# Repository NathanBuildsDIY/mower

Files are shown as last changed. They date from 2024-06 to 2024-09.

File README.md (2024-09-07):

# mower
This is the installation files for version 2 of my automated robot mower. Learn more at the youtube link here:

To set up your raspberry pi zero 2 w

1. If you log in via ssh and it hangs, improve ssh response times with this command and then reboot: echo "IPQoS cs0 cs0" | sudo tee -a /etc/ssh/sshd_config

2. install git on your raspberry pi: sudo apt-get -y install git

3. clone this git repository to your pi home directory: git clone https://github.com/NathanBuildsDIY/mower

4. Run initial setup: nohup sh weeder/initial-setup.sh & Note - you can watch the output with: tail -f nohup.out

5. Connect to the new wifi hostpot called mower. Visit http://mower.local to control your mower.  You can still ssh to the mower (while connected to the mower wifi) via ssh or putty, hostname mower.local

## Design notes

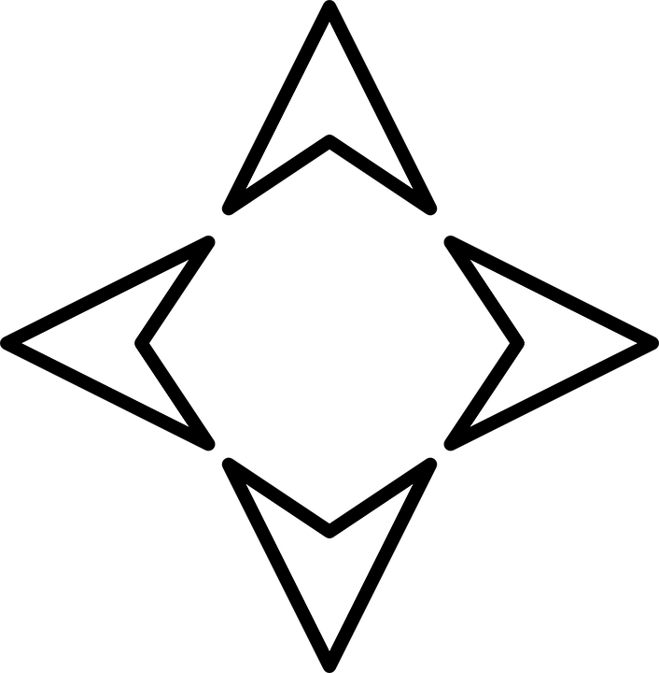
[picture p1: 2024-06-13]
templates/arrows-40162_960_720.png

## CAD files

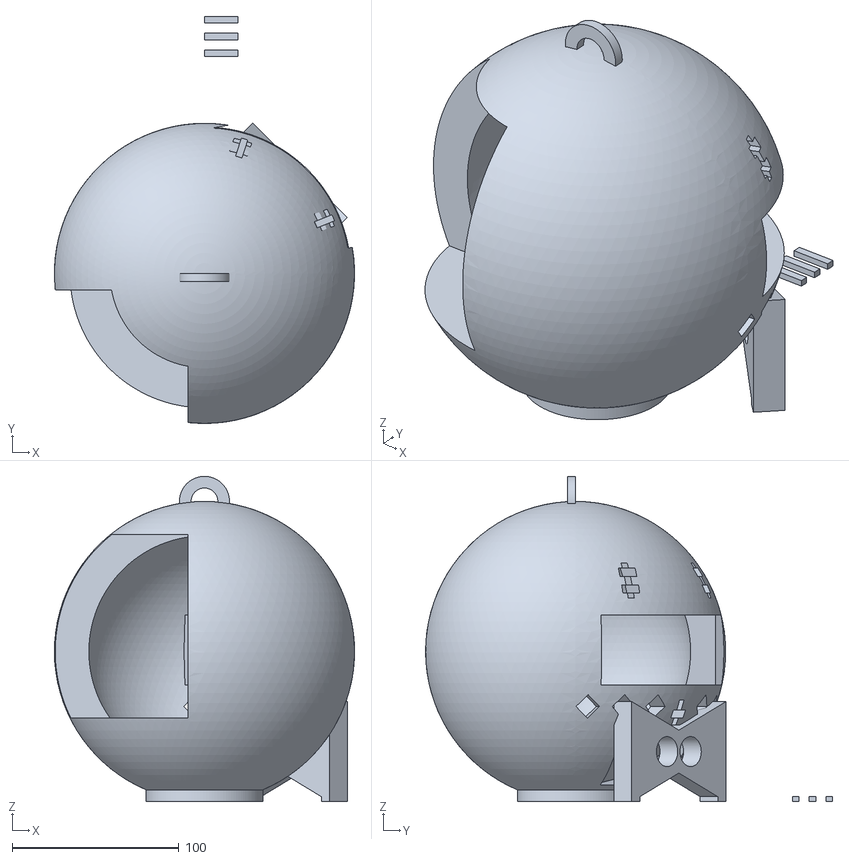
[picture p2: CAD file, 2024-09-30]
ghost_v1.stl
179.9 x 244.0 x 195.0

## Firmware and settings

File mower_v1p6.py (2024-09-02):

#Control for hoverboard function. riorand board. from: #https://mad-ee.com/controlling-a-hoverboard-motor-with-a-simple-arduino/
#run with python3 -m flask --app mower/mower_v1pX.py run --host=0.0.0.0
#1.2 - v2 printed control arms. balance forward w/ curve
#1.3 - forward balance wheels function in robot class, ratio
#1.4 - echo location sensors
#1.5 - 4 wheel drive
#1.6 - pigpio factory. space out readings

# import the necessary packages
from flask import Flask, render_template
import math
import numpy as np
import os
from glob import glob
import time
from datetime import datetime
from gpiozero import Device, PhaseEnableMotor, Robot, PhaseEnableRobot, LED, Servo, AngularServo, Button, DistanceSensor
from gpiozero.tools import zip_values
from gpiozero.pins.pigpio import PiGPIOFactory  
#import py_qmc5883l
from threading import Thread

#TO DO: add object detect/emergency off.
#TO DO: Speed up wheels as battery drains. Count time / wheel turns
#TO DO: auto throttle-off safety. emergency off switch for start/stop on mower.
autoMode=0 #manual mode to start
flask=1 #flask is turned on - so we always start website
speed=0.5 #this is how fast of max (1) we should go. Can adjust if too fast or slow with your wheels. Make programmable?
timeBetweenSensorReads=0.0 #time to wait between reading sensors
timeToFlushSensorHistory=0.85 #how long it will take to completely clear out the sensor array history (how fast the mower reacts to changes in terrain/grass line)
currentCurve_left = 0 #using this as a steering bias if not straight
currentCurve_right = 0
backAdjust_right = 0 #adjust speed of back wheels vs front
backAdjust_left = 0
reactivity = 1 #0 to 1, shows how quickly to react to motors not turning the same speed
max_sensor_distance = 2.0
backWheelAdjust = 1.1 #my back wheels are from a v2 hoverboard and radius is smaller than front. Adjust speed accordingly to cover same distance for front and back tires

#define the wheels and brake pins
brake = LED(14)
brake.off() #this sets nobrake pin high which turns off brake
factory = PiGPIOFactory()
MotorL=PhaseEnableMotor(15,18,pin_factory=factory) #dir,pwm
MotorLBack=PhaseEnableMotor(11,10,pin_factory=factory)
MotorR=PhaseEnableMotor(8,13,pin_factory=factory)
MotorRBack=PhaseEnableMotor(25,22,pin_factory=factory)
MotorLSpeedPin = Button(23); MotorLSpeed = 0
MotorRSpeedPin = Button(7); MotorRSpeed = 0
MotorLBackSpeedPin = Button(9); MotorLBackSpeed = 0
MotorRBackSpeedPin = Button(27); MotorRBackSpeed = 0

#define the sensors
#leftBump = Button(17) #Left bumper, normally True
#rightBump = Button(1) #Right bumper, normally True
rightGrass = DistanceSensor(echo=12, trigger=16, max_distance=max_sensor_distance,pin_factory=factory) #Right grass, normally False
rightCenterGrass = DistanceSensor(echo=20, trigger=21, max_distance=max_sensor_distance,pin_factory=factory) #Right Center grass, normally False
leftGrass = DistanceSensor(echo=19, trigger=26, max_distance=max_sensor_distance,pin_factory=factory) #Left Center grass, normally False
leftCenterGrass = DistanceSensor(echo=6, trigger=5, max_distance=max_sensor_distance,pin_factory=factory) #Left grass, normally False
currentTime=datetime.now()

#Use this with object detect/avoid - need to turn a know number of degrees to go around stuff
'''#define the compass.  Here's some notes about it. It's not HMC as advertised
#from https://forums.raspberrypi.com//viewtopic.php?f=28&t=172244 -- this is QMC not HMC, that's not made any more bottom of page get drivers: https://github.com/RigacciOrg/py-qmc5883l
#PINS: vcc (yellow) -> 3.3V pin1.  Gnd Green -> Gnd pin 9.  orange SCL -> GPIO3 (pin5). red SDA->GPIO2 (pin3). DRDY unused.
#Don't connect drdy to any wire, it caused xy axis to shift to yz axis. compass broke!
#Enable I2C: sudo raspi-config (activate it under interfaces->i2c)
#Check connected up: sudo i2cdetect -y 1  (see output) - 0d address
#cd ~/mower/; git clone https://github.com/RigacciOrg/py-qmc5883l
#add py-qmc5883l to python path variable
  #sudo vi /etc/profile
  #At the top add these two lines (adjust path if necessary):
  #export ADDPATH=/home/gibby/mower/py-qmc5883l
  #export PYTHONPATH=$PYTHONPATH:$ADDPATH
  #reboot
#sensor = py_qmc5883l.QMC5883L()
#m = sensor.get_magnet()
#print(m)
'''

#easier to define our own since we have specific needs for forward (balance all 4 wheel rotation speeds) etc.
class mowerRobot:
  def __init__(self, leftMotor, rightMotor, leftBackMotor, rightBackMotor):
    self.left_motor=leftMotor
    self.right_motor=rightMotor
    self.leftBack_motor=leftBackMotor
    self.rightBack_motor=rightBackMotor
  def forward(self, speed=1, *, curve_left=0, curve_right=0, previousCommand="straight", command="straight", intentionalAngle=False):
    global MotorRSpeed, MotorLSpeed, MotorRBackSpeed, MotorLBackSpeed, currentCurve_right, currentCurve_left,backAdjust_right, backAdjust_left
    saveCounts=""
    #check if wheels are turning at the same speed. 
    if (previousCommand == "straight" and command == "straight") or (previousCommand == "angleR" and command == "angleR") or (previousCommand == "angleL" and command == "angleL"):
      saveCounts = "FRC: "+str(MotorLSpeed)+" FRC: "+str(MotorRSpeed)+" BLC: "+str(MotorLBackSpeed)+" BRC: "+str(MotorRBackSpeed)
      #we've been going straight for at least 2 commands, or angling for 2 commands. We can check wheel counts and recalculate speeds if counts are high enough.
      if MotorRSpeed > 25 or MotorLSpeed > 25:
        #only recalculate if we have enough turns to call it "valid". Start with front wheels
        if MotorRSpeed*(1-curve_left) < MotorLSpeed*(1-curve_right):
          #right side is turning slower. add to right speed or subtract from left
          #If command=straight curve_left and right are 0 so its direct wheel compare. 
          #If command=angleL motorRSpeed (count of wheel turns on front R) shoudl be bigger, curve_left is .2 so it's motorRSpeed * .8 compared to motorLSpeed. angleR vice versa
          adder = round((MotorLSpeed*(1-curve_right)) / ((MotorRSpeed+1)*(1-curve_left)) * speed - speed,2) * reactivity
          if currentCurve_left > 0:
            currentCurve_left = round(currentCurve_left - adder,2)
            currentCurve_right = 0
          else:
            currentCurve_right = round(currentCurve_right + adder,2)
            currentCurve_left = 0
        if MotorRSpeed*(1-curve_left) > MotorLSpeed*(1-curve_right):
          #left side is turning slower. add to left side speed or subtract from right
          adder = round((MotorRSpeed*(1-curve_left)) / ((MotorLSpeed+1) * (1-curve_right)) * speed - speed,2) * reactivity
          if currentCurve_right > 0:
            currentCurve_right = round(currentCurve_right - adder,2)
            currentCurve_left = 0
          else:
            currentCurve_left = round(currentCurve_left + adder,2)
            currentCurve_right = 0
        if currentCurve_left < 0:
          currentCurve_left = 0 #we can get negatives if we subtract as such above, can't set curve negative
        if currentCurve_right < 0:
          currentCurve_right = 0
        #Now figure out back wheel speeds
        backAdjust_right = round(((MotorRSpeed*backWheelAdjust)/(MotorRBackSpeed+1) - 1) * reactivity/4,2) #positive if front wheel is too fast, so add ot back wheel speed
        backAdjust_left = round(((MotorLSpeed*backWheelAdjust)/(MotorLBackSpeed+1) - 1) * reactivity/4,2)
        #we corrected speeds. Reset counts to 0
        MotorRSpeed = 0; MotorLSpeed = 0; MotorLBackSpeed = 0; MotorRBackSpeed = 0
        #saveCounts = saveCounts +" Adj+0 "
    else:
      #just moved from turning or backing or something else to straight. don't pay attention to wheel counts, instead 0 them out and start recounting
      MotorRSpeed = 0; MotorLSpeed = 0; MotorLBackSpeed = 0; MotorRBackSpeed = 0
      saveCounts = "FRC: "+str(MotorLSpeed)+" FRC: "+str(MotorRSpeed)+" BLC: "+str(MotorLBackSpeed)+" BRC: "+str(MotorRBackSpeed)+" 0-dir "
    saveCounts = saveCounts+" FRA: "+str(currentCurve_right)+" FLA: "+str(currentCurve_left)+" BRA: "+str(backAdjust_right)+" BLA: "+str(backAdjust_left)
    #execute the drive command with the calculated values after error checks
    if not 0 <= curve_left <= 1:
      raise ValueError('curve_left must be between 0 and 1')
    if not 0 <= curve_right <= 1:
      raise ValueError('curve_right must be between 0 and 1')
    if curve_left != 0 and curve_right != 0:
      raise ValueError("curve_left and curve_right can't be used at the same time")
    frontLeftSpeed = round((speed + currentCurve_left) * (1 - curve_left),2)
    frontRightSpeed =round((speed + currentCurve_right) *(1 - curve_right),2)
    backLeftSpeed = round(frontLeftSpeed + backAdjust_left,2)
    backRightSpeed = round(frontRightSpeed + backAdjust_right,2)
    if not 0 <= frontLeftSpeed:
      frontLeftSpeed = 0
    if not frontLeftSpeed <= 1:
      frontLeftSpeed = 1
    if not 0 <= frontRightSpeed:
      frontRightSpeed = 0
    if not frontRightSpeed <=1:
      frontRightSpeed = 1
    if not 0 <= backLeftSpeed:
      backLeftSpeed = 0
    if not backLeftSpeed <=1:
      backLeftSpeed = 1
    if not 0 <= backRightSpeed:
      backRightSpeed = 0
    if not backRightSpeed <=1:
      backRightSpeed = 1
    self.left_motor.forward(frontLeftSpeed); 
    self.right_motor.forward(frontRightSpeed);
    self.leftBack_motor.forward(backLeftSpeed)
    self.rightBack_motor.forward(backRightSpeed)
    return "F-FLS:"+str(frontLeftSpeed)+" FRS:"+str(frontRightSpeed)+" BLS:"+str(backLeftSpeed)+" BRS:"+str(backRightSpeed)+" ",saveCounts
  def backward(self, speed=1, *, curve_left=0, curve_right=0):
    global MotorRSpeed, MotorLSpeed, MotorRBackSpeed, MotorLBackSpeed, currentCurve_right, currentCurve_left,backAdjust_right, backAdjust_left
    frontLeftSpeed = round((speed + currentCurve_left) * (1 - curve_left),2)
    frontRightSpeed =round((speed + currentCurve_right) *(1 - curve_right),2)
    backLeftSpeed = round(frontLeftSpeed + backAdjust_left,2)
    backRightSpeed = round(frontRightSpeed + backAdjust_right,2)
    if not 0 <= frontLeftSpeed:
      frontLeftSpeed = 0
    if not frontLeftSpeed <= 1:
      frontLeftSpeed = 1
    if not 0 <= frontRightSpeed:
      frontRightSpeed = 0
    if not frontRightSpeed <=1:
      frontRightSpeed = 1
    if not 0 <= backLeftSpeed:
      backLeftSpeed = 0
    if not backLeftSpeed <=1:
      backLeftSpeed = 1
    if not 0 <= backRightSpeed:
      backRightSpeed = 0
    if not backRightSpeed <=1:
      backRightSpeed = 1
    self.left_motor.backward(frontLeftSpeed); 
    self.right_motor.backward(frontRightSpeed);
    self.leftBack_motor.backward(backLeftSpeed)
    self.rightBack_motor.backward(backRightSpeed)
    print("B-FLS:",str(frontLeftSpeed),"FRS:",str(frontRightSpeed),"BLS:",str(backLeftSpeed),"BRS:",str(backRightSpeed),"FLC:",MotorLSpeed,"FRC:",MotorRSpeed,"BLC:",MotorLBackSpeed,"BRC:",MotorRBackSpeed)
  def left(self, speed=1):
    global MotorRSpeed, MotorLSpeed, MotorRBackSpeed, MotorLBackSpeed, currentCurve_right, currentCurve_left,backAdjust_right, backAdjust_left
    self.left_motor.backward(1)
    self.right_motor.forward(1)
    self.leftBack_motor.backward(1)
    self.rightBack_motor.forward(1)
    print("L-FLS:1.0 FRS:1.0 BLS:1.0 BRS:1.0")
  def right(self, speed=1):
    global MotorRSpeed, MotorLSpeed, MotorRBackSpeed, MotorLBackSpeed, currentCurve_right, currentCurve_left,backAdjust_right, backAdjust_left
    self.left_motor.forward(1)
    self.right_motor.backward(1)
    self.leftBack_motor.forward(1)
    self.rightBack_motor.backward(1)
    print("R-FLS:1.0 FRS:1.0 BLS:1.0 BRS:1.0ba")
  def stop(self):
    self.left_motor.stop()
    self.right_motor.stop()
    self.leftBack_motor.stop()
    self.rightBack_motor.stop()
    print("S-FLS:0.0 FRS:0.0 BLS:0.0 BRS:0.0")
robot = mowerRobot(MotorL,MotorR,MotorLBack,MotorRBack)

#useful functions
#To be used with compass and object detect/avoid
'''def turnMower(direction,degrees):
  initialCompass=sensor.get_bearing()
  currentCompass=initialCompass
  if direction == "right":
    robot.right(speed); 
  else:
    robot.left(speed);
  while abs(initialCompass-currentCompass) % 360 < degrees or abs(initialCompass-currentCompass) % 360 > (360-degrees):
    time.sleep(0.02); 
    currentCompass=sensor.get_bearing()
  print("initial compass:",str(initialCompass),"currentCompass",str(currentCompass),"difference",str(abs(initialCompass-currentCompass)%360))
'''
def sensorWeightedAverage(grassSensor):
  global grassSide
  numMeasurements=len(grassSensor) #number of measurements
  numSensors=len(grassSensor[0]) #number of sensors on mower
  #get the weights based on number of measurements
  linArr = np.arange(1, numMeasurements+1)
  arrSum = numMeasurements * (numMeasurements+1) // 2
  reverseWeights = linArr/arrSum
  #row by row add up the weighted values in columns
  weightedGrassSensor = [0] * numSensors
  for (i,row) in enumerate(grassSensor):
    for (j,value) in enumerate(row):
      if value == max_sensor_distance * 100:
        value = 2.0 #we only get max sensor distance when no echo comes back, because grass is pressed right up on sensor. Correct for this
      weightedGrassSensor[j]=weightedGrassSensor[j]+reverseWeights[numMeasurements-1-i]*value
  #sum up the values in columns - unused
  #sumGrassSensor=[sum(x) for x in zip(*grassSensor)]
  for i in range(numSensors):
    weightedGrassSensor[i]=round(weightedGrassSensor[i],2)
  return weightedGrassSensor

#Add back in with object detect/avoid
'''
#interrupts wheels and obstacles.  Take over wheels to move around obstacle.
def opticalBumpPress(initiator):
  global grassSide, interrupt, brake, robot, leftBump, rightBump
  duration = 1 #number of seconds to drive sideways to avoid the obstacle
  print("Starting avoidance routine, bumped by:",initiator)
  if interrupt == 0:
    interrupt=1 #tells the robot to stop doing other stuff
    #First try to back up and ensure the beam break is undone. If it's not, just stop. Could be the operator wants to stop the robot
    print("avoid obstacle - #1 brake"); brake.on(); time.sleep(0.1); robot.stop(); brake.off(); #first, stop things
    print("2 back up"); robot.backward(speed); time.sleep(2); brake.on(); time.sleep(0.1); robot.stop(); brake.off(); #second back up
    if leftBump.is_pressed and rightBump.is_pressed:
      print("3 turn opposite ",grassSide)
      if grassSide == "left":
        turnMower("right",90)
      else:
        turnMower("left",90)
      brake.on(); time.sleep(0.1); robot.stop(); brake.off(); #third turn 90
      print("4 forward for ",str(duration)); robot.forward(speed); time.sleep(duration); brake.on(); time.sleep(0.1); robot.stop(); brake.off(); #fourth drive forward (around obstacle)
      print("5 turn ",grassSide)
      turnMower(grassSide,90)
      time.sleep(1); brake.on(); time.sleep(0.1); robot.stop(); brake.off(); #fifth turn 90 back to original direction 
      print("6 return control to main loop")
    else:
      print("can't reestablish the bumper connection after backup, quitting")
      autoMode = 0
      robot.stop()
  interrupt = 0
  return
'''
def MotorLSpeedCount():
  global MotorLSpeed, MotorLSpeedPin
  MotorLSpeed = MotorLSpeed + 1
def MotorRSpeedCount():
  global MotorRSpeed, MotorRSpeedPin
  MotorRSpeed = MotorRSpeed + 1
def MotorLBackSpeedCount():
  global MotorLBackSpeed, MotorLBackSpeedPin
  MotorLBackSpeed = MotorLBackSpeed + 1
def MotorRBackSpeedCount():
  global MotorRBackSpeed, MotorRBackSpeedPin
  MotorRBackSpeed = MotorRBackSpeed + 1
#create calls to interrupts
#opticalBump.when_pressed = opticalBumpPress #activates "pressed" when object breaks beam
#leftBump.when_released = opticalBumpPress #activates "released" when object depresses sensor bar
#rightBump.when_released = opticalBumpPress #activates "released" when object depresses sensor bar
MotorLSpeedPin.when_pressed = MotorLSpeedCount
MotorRSpeedPin.when_pressed = MotorRSpeedCount
MotorLBackSpeedPin.when_pressed = MotorLBackSpeedCount
MotorRBackSpeedPin.when_pressed = MotorRBackSpeedCount
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

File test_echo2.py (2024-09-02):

#!/usr/bin/python

from gpiozero import Device, PhaseEnableMotor, Robot, PhaseEnableRobot, LED, Servo, AngularServo, Button, DistanceSensor
from gpiozero.tools import zip_values
from gpiozero.pins.pigpio import PiGPIOFactory  
from time import sleep

factory = PiGPIOFactory()
rightGrass = DistanceSensor(echo=12, trigger=16, max_distance=2.0,pin_factory=factory) #Right grass, normally False
rightCenterGrass = DistanceSensor(echo=20, trigger=21, max_distance=2.0,pin_factory=factory) #Right Center grass, normally False
leftGrass = DistanceSensor(echo=19, trigger=26, max_distance=2.0,pin_factory=factory) #Left Center grass, normally False
leftCenterGrass = DistanceSensor(echo=6, trigger=5, max_distance=2.0,pin_factory=factory) #Left grass, normally False

while True:
   l = str(round(leftGrass.distance * 100,1))
   sleep(0.05)
   lc = str(round(leftCenterGrass.distance * 100,1))
   sleep(0.05)
   rc = str(round(rightCenterGrass.distance * 100,1))
   sleep(0.05)
   r = str(round(rightGrass.distance * 100,1))
   sleep(0.05)
   print("left:",l,"leftCenter",lc,"rightCenter",rc,"right",r)

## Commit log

2024-09-02 working with ultrasonic sensors
2024-09-02 Delete test_motors.py
    unused test - just use main webpage to test motor function
2024-09-08 Add files via upload
    schematics etc.
